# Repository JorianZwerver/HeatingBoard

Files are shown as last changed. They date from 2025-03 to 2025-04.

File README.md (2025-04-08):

# Heating Board PCB

PCB for MOD11 project. Measures current of four channels and can PWM each channel using a PMOS circuit. 

Schematic: [Schematic](Exports/HeatingBoard.pdf) \
Test results: [Results](Testing/2025_03_31_Test_Plan_Heating_Board_Execution.pdf) \
Test code for Arduino Uno: [Code](Testing/test_code.ino)

## Implementation

The board has 5 connectors:

| Connector ID | Description |
| --- | --- |
| J1 | Battery connector, is used for power. |
| J2 | Input interface for control, has a PWM pin for each group and the input for the 3V3 power. |
| J3 | I2C connector, contains SDA, SCL and GND. **However, the GND pin is broken and does not work.** |
| J4 | I2C connector, contains SDA, SCL and GND. |
| J5 | Output to the heating sleeve. Has four outputs and a GND that power the sleeve. |

### Current sensors

The current sensors communicate over the I2C bus. They need 3V3 power, but not battery power. The addresses are stated below:

| Channel number | Address (HEX) | Address (BIN) | Shunt resistor value (mOhm) |
| --- | --- | --- | --- |
| 1 | 0x45 | 1000101 | 101 |
| 2 | 0x44 | 1000100 | 101.2 |
| 3 | 0x41 | 1000001 | 100.5 |
| 4 | 0x40 | 1000000 | 100.6 |

The datasheet can be found using this [link](https://www.ti.com/lit/ds/symlink/ina219.pdf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). We have tested the current sensors in combination with a small load and encountered problems with the PWM, since the current sensor would sometimes measure the full current and sometimes zero current. To solve this, we increased the sample size and PWM frequency. This does mean that the sensor takes ~ 70 ms to get new data. We recommend the following settings:

- 12 bit shunt resolution
- 128 samples per measurement
- 2.5 kHz PWM frequency

We have found pretty accurate results using these settings, only deviating a couple of mW from the power supply. The testing code can be found [here](Testing/test_code.ino). The resistor values of the current shunts are shown in the table with the addresses for the current sensors.

### MOSFETs

During testing, we found that the duty cycle of the output voltage starts deviating from the input duty cycle for higher PWM frequencies. We have tested this for frequencies of 2.5, 5 and 10 kHz and we recommend 2.5 kHz. All results can be found in the [test report](Testing/2025_03_31_Test_Plan_Heating_Board_Execution.pdf).

## 3D Images

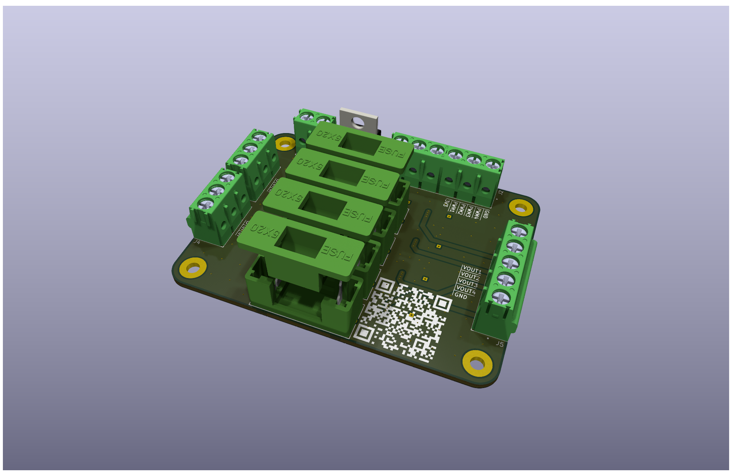
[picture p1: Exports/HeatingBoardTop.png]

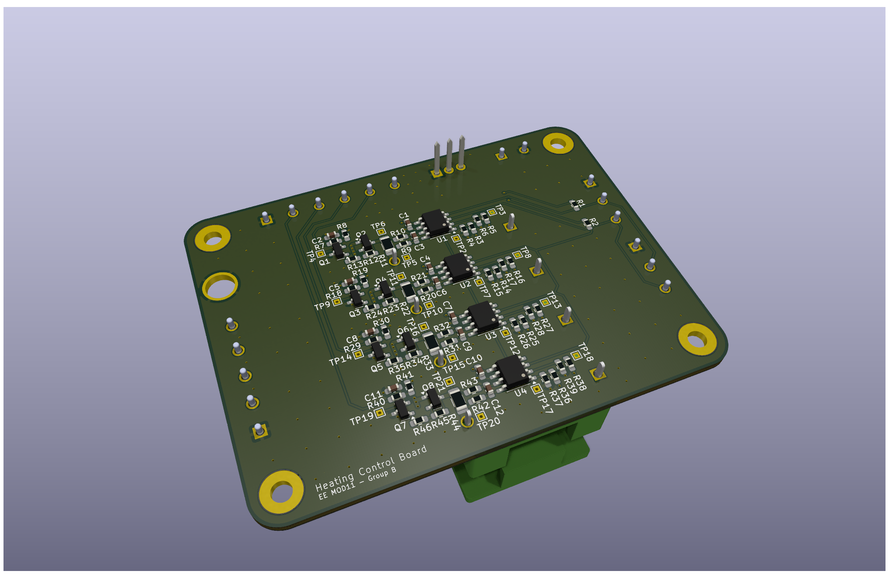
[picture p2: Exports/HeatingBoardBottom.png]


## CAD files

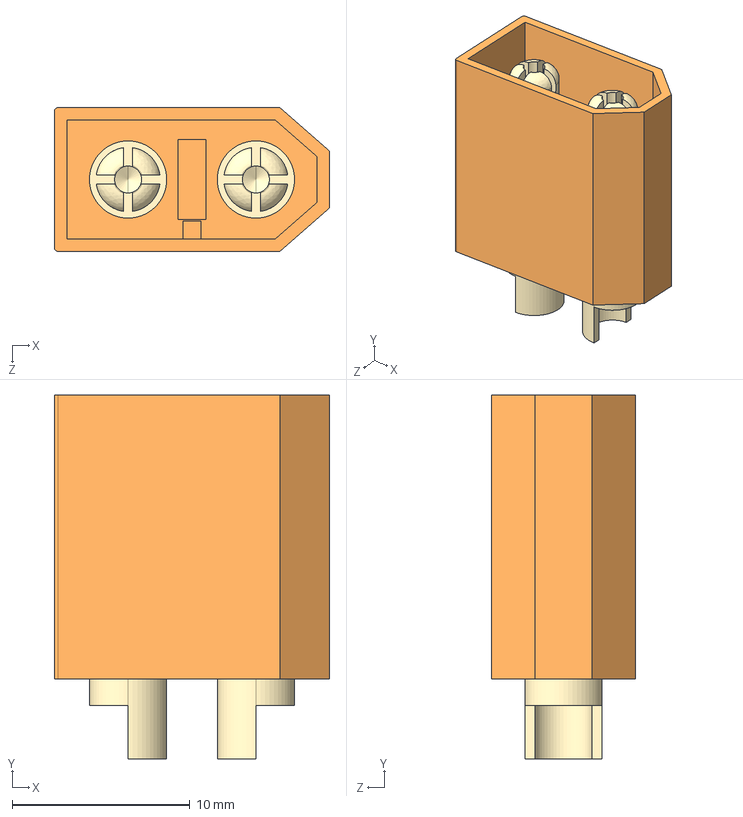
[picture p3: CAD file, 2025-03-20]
HeatingBoard3D/XT60-M.step
15.5 x 20.5 x 8.10 mm

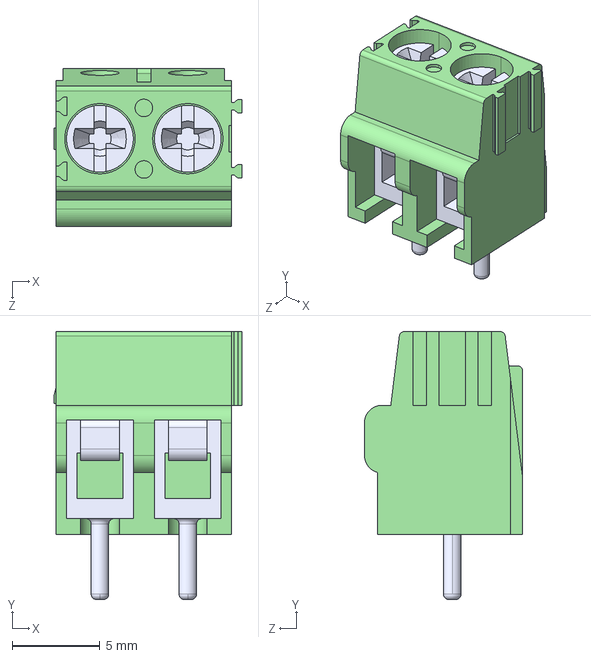
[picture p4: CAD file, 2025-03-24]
HeatingBoard3D/1935161/1935161.step
10.7 x 15.2 x 9.00 mm

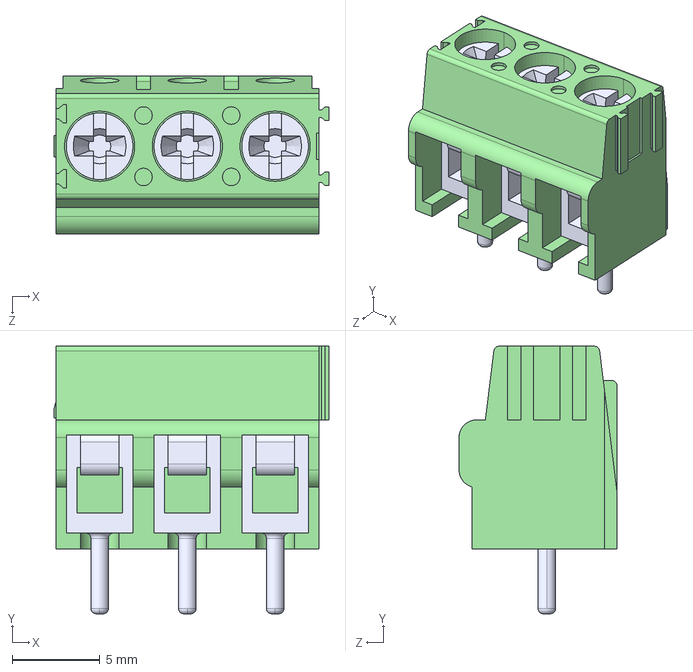
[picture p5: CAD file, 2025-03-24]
HeatingBoard3D/1935174/1935174.step
15.7 x 15.2 x 9.00 mm

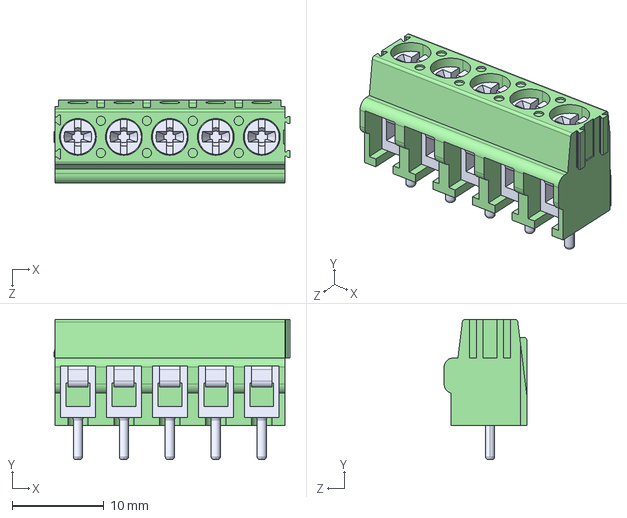
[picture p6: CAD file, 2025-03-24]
HeatingBoard3D/1935190/1935190.step
25.7 x 15.2 x 9.00 mm

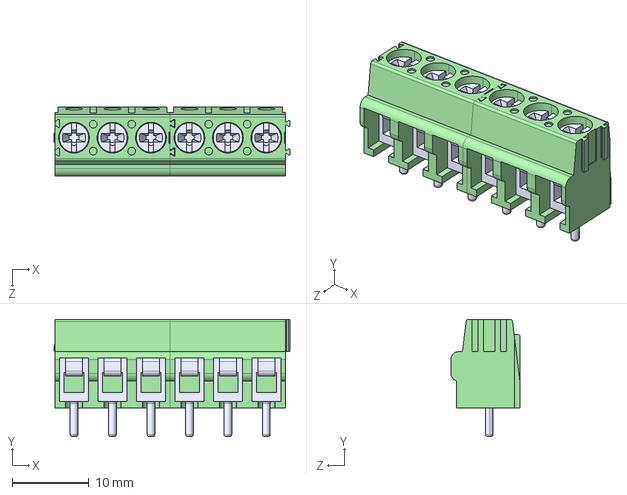
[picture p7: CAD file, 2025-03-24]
HeatingBoard3D/1935200/1935200.step
30.7 x 15.3 x 9.00 mm
1935200_Body_1935174 x 2

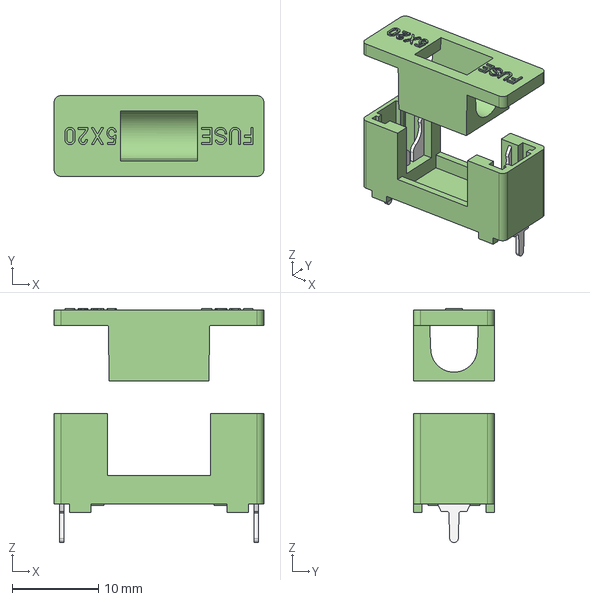
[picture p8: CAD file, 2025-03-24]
HeatingBoard3D/696108003002 (rev1).stp
24.4 x 9.40 x 27.2 mm

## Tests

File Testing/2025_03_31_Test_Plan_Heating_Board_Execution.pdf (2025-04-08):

# Test Plan Heating Board

## Made on March 31st, 2025

Testers: | Jorian Zwerver & Tom Kroeze
Date: | 7th of april 2025
PCB nr.: | 1

## Used devices

Write down below the serial number of the required devices for testing

Benodigdheden | Typenummer
Multimeter | EDU34450A
Power supply | EDU36311A
Load | 2x 200 Ω THT resistors in parallel
Oscilloscope | DSOX1204G

## Hardware testing

### Assembly

Test | Channel 1 | Channel 2 | Channel 3 | Channel 4
Quality of the soldering | Quality of the soldering was good, connection between ground and J3 missing because of a broken pin.
Orientation IC’s | Correct.
Resistor R11 (mΩ) | 101 ± 0.1 | 101.2 ± 0.1 | 100.5 ± 0.1 | 100.6 ± 0.05
No short between 3V3 and GND | Correct.
No short between input and GND | Correct.
No short between output and ground GND | Correct | Correct | Correct | Correct
Resistor between 3V3 and SDA (kΩ) | 2.199
Resistor between 3V3 and | 2.197

SCL (kΩ)

## Power supply

Place 3.3V on J2 and continue the measurements

Test | Channel 1 | Channel 2 | Channel 3 | Channel 4
Measure voltage on IC’s | 3.3V | 3.3V | 3.3V | 3.3V
Measure voltage on TP2 (A1) | 3.3V | 3.3V | 0V | 0V
Measure voltage on Tp3 TP3 (A0) | 3.3V | 0V | 3.3V | 0V

### MOSFETs

Test | Channel 1 | Channel 2 | Channel 3 | Channel 4
Resistor between TP6 and VOUT, PWM = 0V | Open | Open | Open | Open
Resistor between TP6 and VOUT, PWM = 3V3, 0.1 A load | 93 mΩ | 93.5 mΩ | 93.8 mΩ | 92 mΩ

## Function testing

### INA219

Connect the board through the J3 or J4 to the Arduino to test the communication with the INA219 chips.

Test | Channel 1 | Channel 2 | Channel 3 | Channel 4
Test if I2C communication is present | Correct. | Correct. | Correct. | Correct.
Measured current @ 0.1 A (assuming 0.1 Ω resistor) | 0.102 ± 0.001 A | 0.102 ± 0.001 A | 0.099 ± 0.001 A | 0.100 ± 0.001 A

### MOSFETs

Now also connect the J2 to the Arduino to test the MOSFETs. Pull 100 mA with the load. PWM frequency is 5 kHz, duty cycle is at 25%

Test | Channel 1 | Channel 2 | Channel 3 | Channel 4

Measure Vout with an
oscilloscope, is there a
neat squarewave at the
output?
Correct. | Correct. | Correct. | Correct.

## General remarks

Some issues were encountered during testing. Both the issue and the solution will be discussed in this section.

Current sensor measurements in combination with PWM
Due to the use of PWM, the current sensor will sometimes measure no current, and at other moments all the current. This results in an inconsistent measurement. To solve this, the frequency of the PWM is increased and the amount of samples per measurement is increased. This resulted in a better average measurement, which resulted in a current that was of similar accuracy as the power supply.

Used settings:
- 12 bit bus resolution
- 128 samples per measurement
- 5 kHz PWM frequency

Turn-off time PMOS
With the initial testing, at a frequency of around 5 kHz, the turnoff speed of the mosfet was slower than expected. This resulted in the actual duty cycle not properly aligning with the input duty cycle. Because it was slower than expected, the output duty cycle ended up being higher than the input duty cycle which should not be the case. This effect is shown in figures 1 and 2. To prevent this effect from happening, firstly R13 was set to 0Ω and R12 was changed to a 2.2kΩ resistor. Changing these resistors should lead to the Mosfet discharging faster, thus reducing the turn-off time. This seemed to resolve the issue, however, when measuring the 4th channel the current sensor values were producing confusing results. We believe this was caused by some EMI problems by very high turn-off or turn-on times. Because of this, the 0Ω resistor was changed to a 2.2kΩ resistor which solved the problem. This resulted in figures 3 to 6.

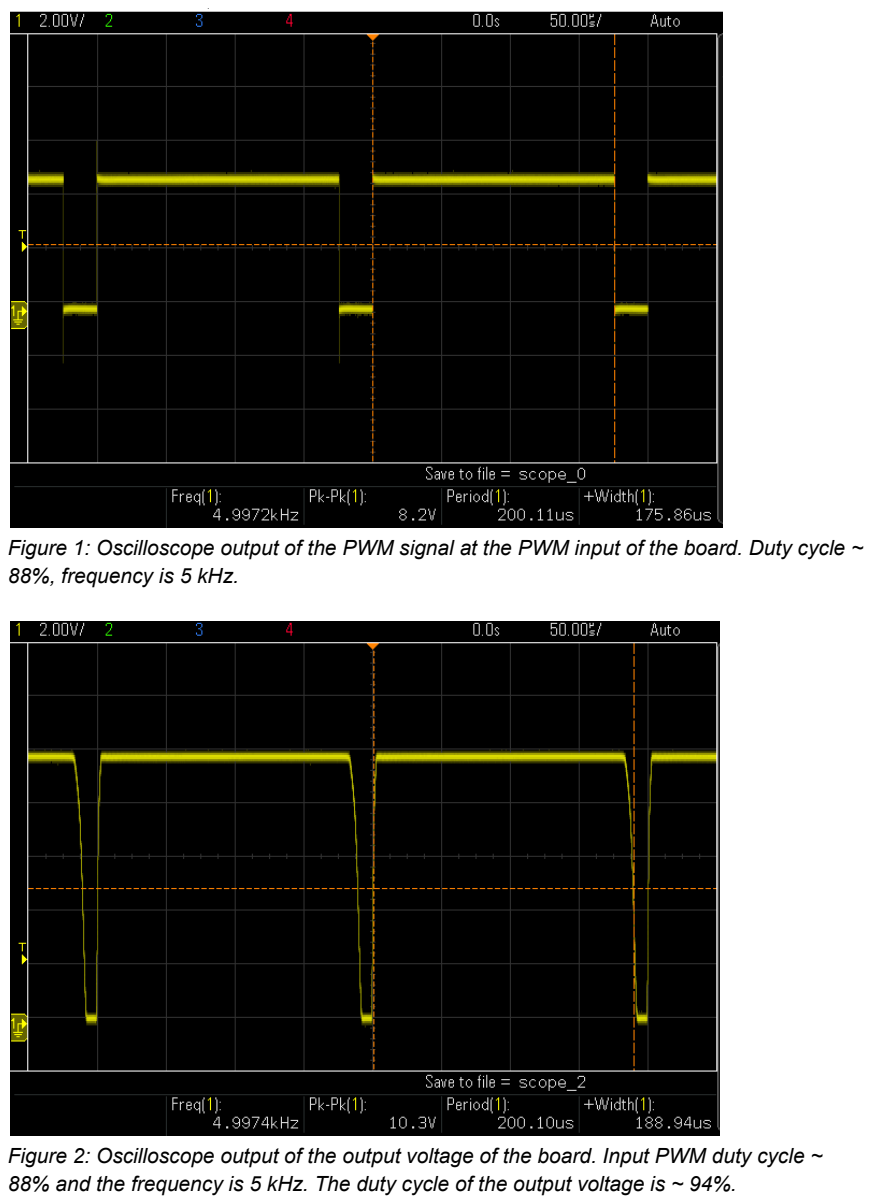
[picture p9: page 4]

Figure 1: Oscilloscope output of the PWM signal at the PWM input of the board. Duty cycle ~ 88%, frequency is 5 kHz.

Figure 2: Oscilloscope output of the output voltage of the board. Input PWM duty cycle ~ 88% and the frequency is 5 kHz. The duty cycle of the output voltage is ~ 94%.

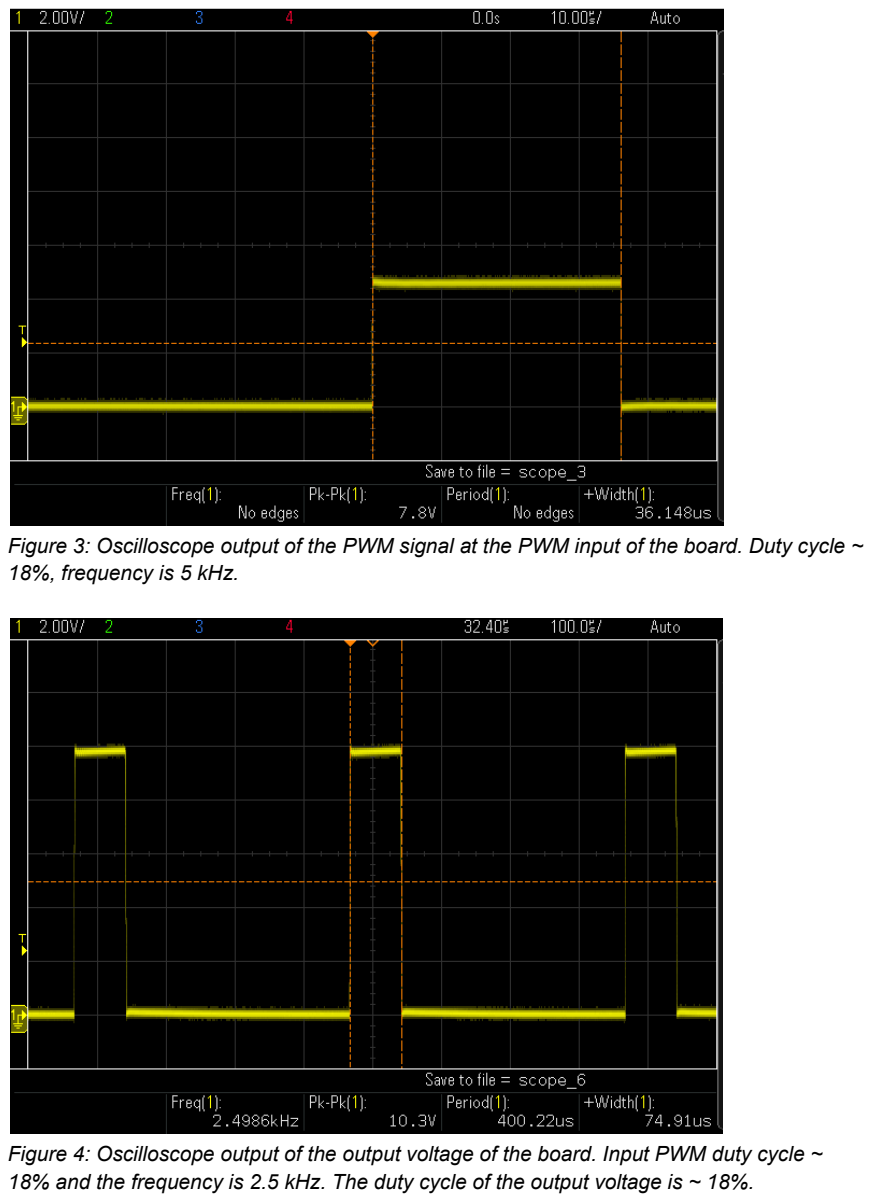
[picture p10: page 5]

Figure 3: Oscilloscope output of the PWM signal at the PWM input of the board. Duty cycle ~ 18%, frequency is 5 kHz.

Figure 4: Oscilloscope output of the output voltage of the board. Input PWM duty cycle ~ 18% and the frequency is 2.5 kHz. The duty cycle of the output voltage is ~ 18%.

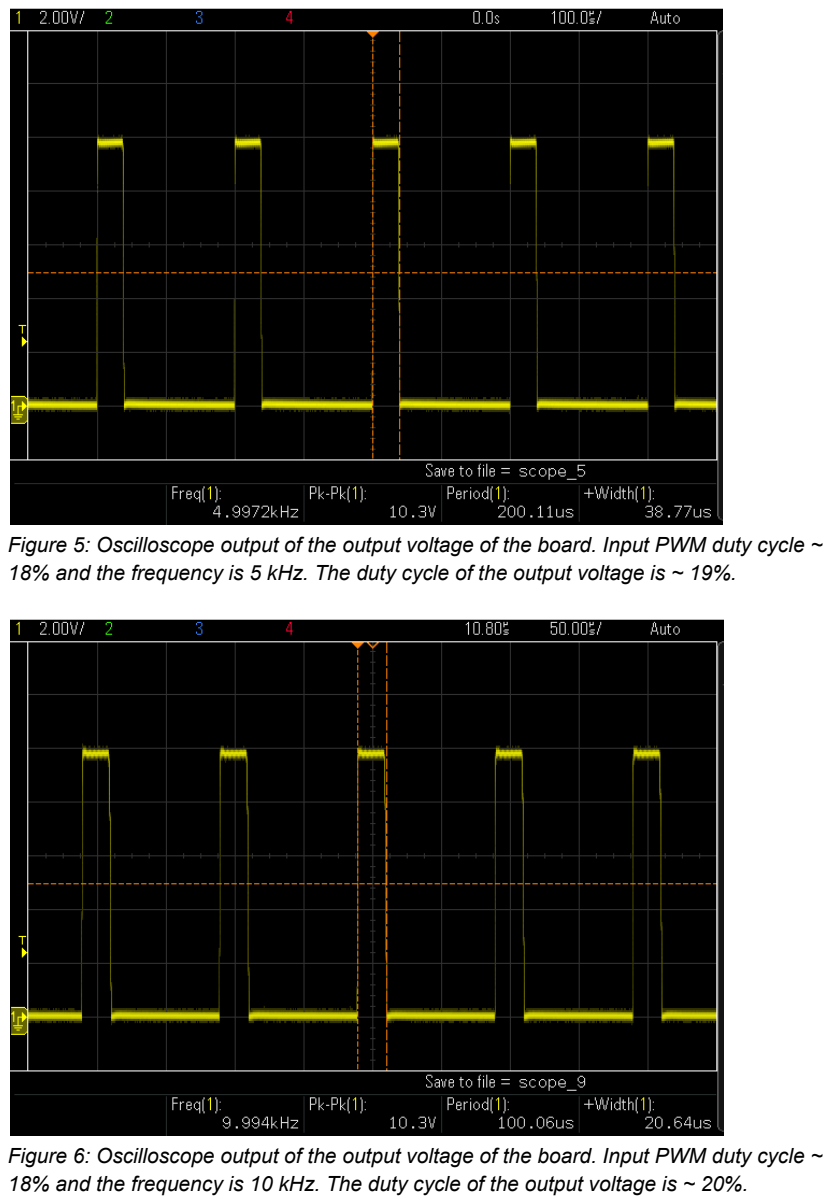
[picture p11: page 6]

Figure 5: Oscilloscope output of the output voltage of the board. Input PWM duty cycle ~ 18% and the frequency is 5 kHz. The duty cycle of the output voltage is ~ 19%.

Figure 6: Oscilloscope output of the output voltage of the board. Input PWM duty cycle ~ 18% and the frequency is 10 kHz. The duty cycle of the output voltage is ~ 20%.

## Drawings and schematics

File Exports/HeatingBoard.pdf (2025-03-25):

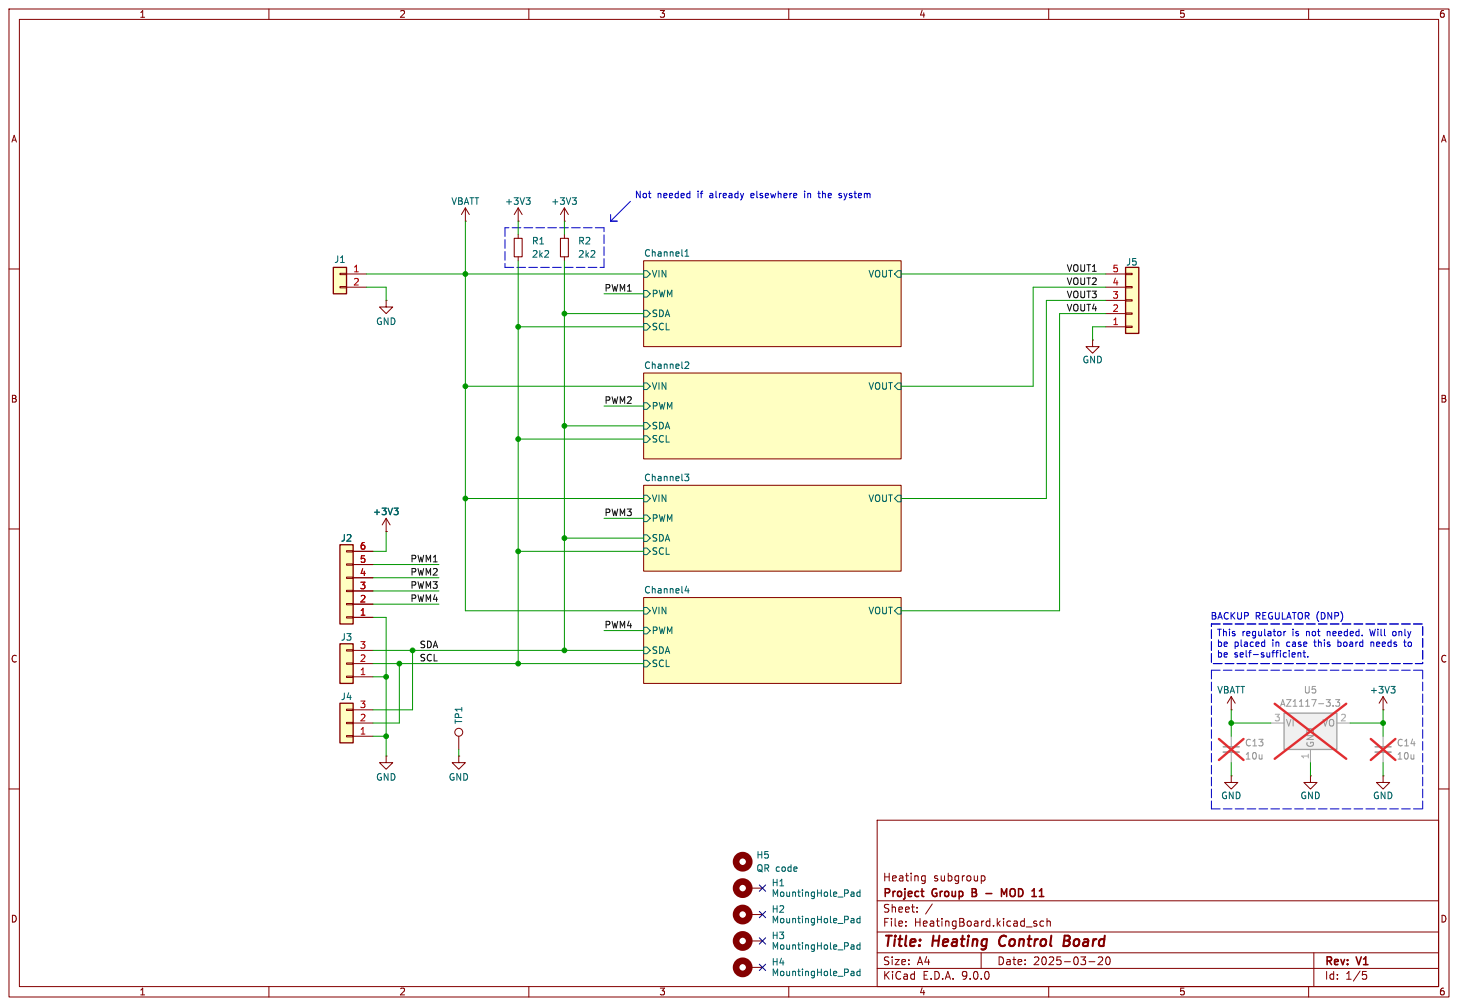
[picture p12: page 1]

be self-sufficient. Not needed if already elsewhere in the system

Id: 1/5 Title: Heating Control Board

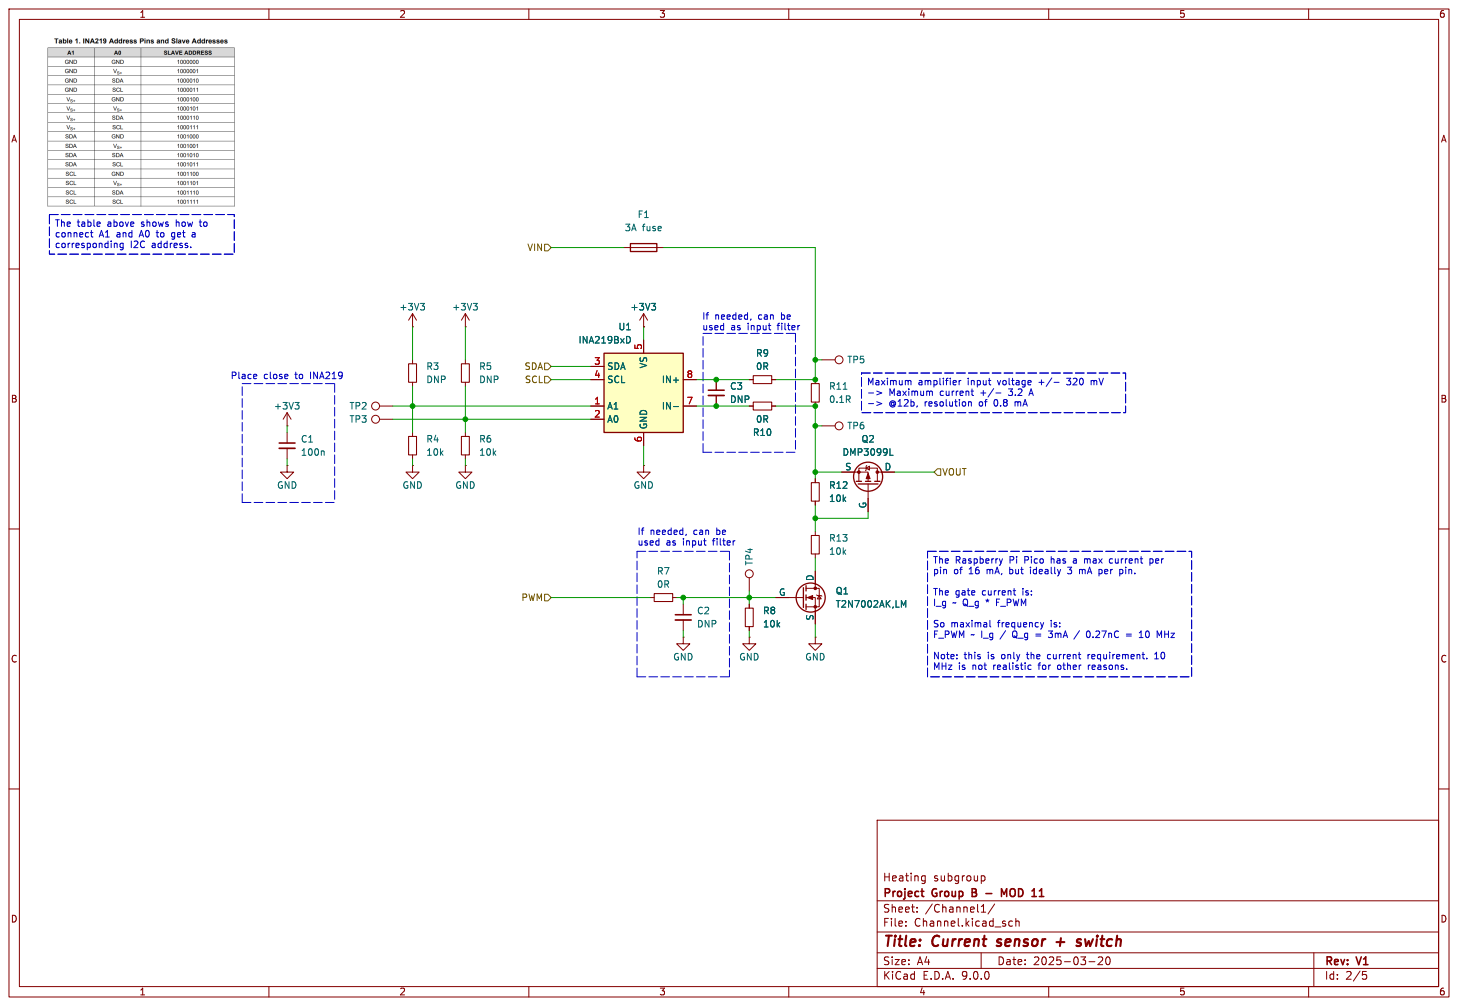
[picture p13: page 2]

The table above shows how to
connect A1 and A0 to get a

used as input filter +3V3 U1

If needed, can be
used as input filter

The Raspberry Pi Pico has a max current per pin of 16 mA, but ideally 3 mA per pin. The gate current is:

Id: 2/5 Title: Current sensor + switch

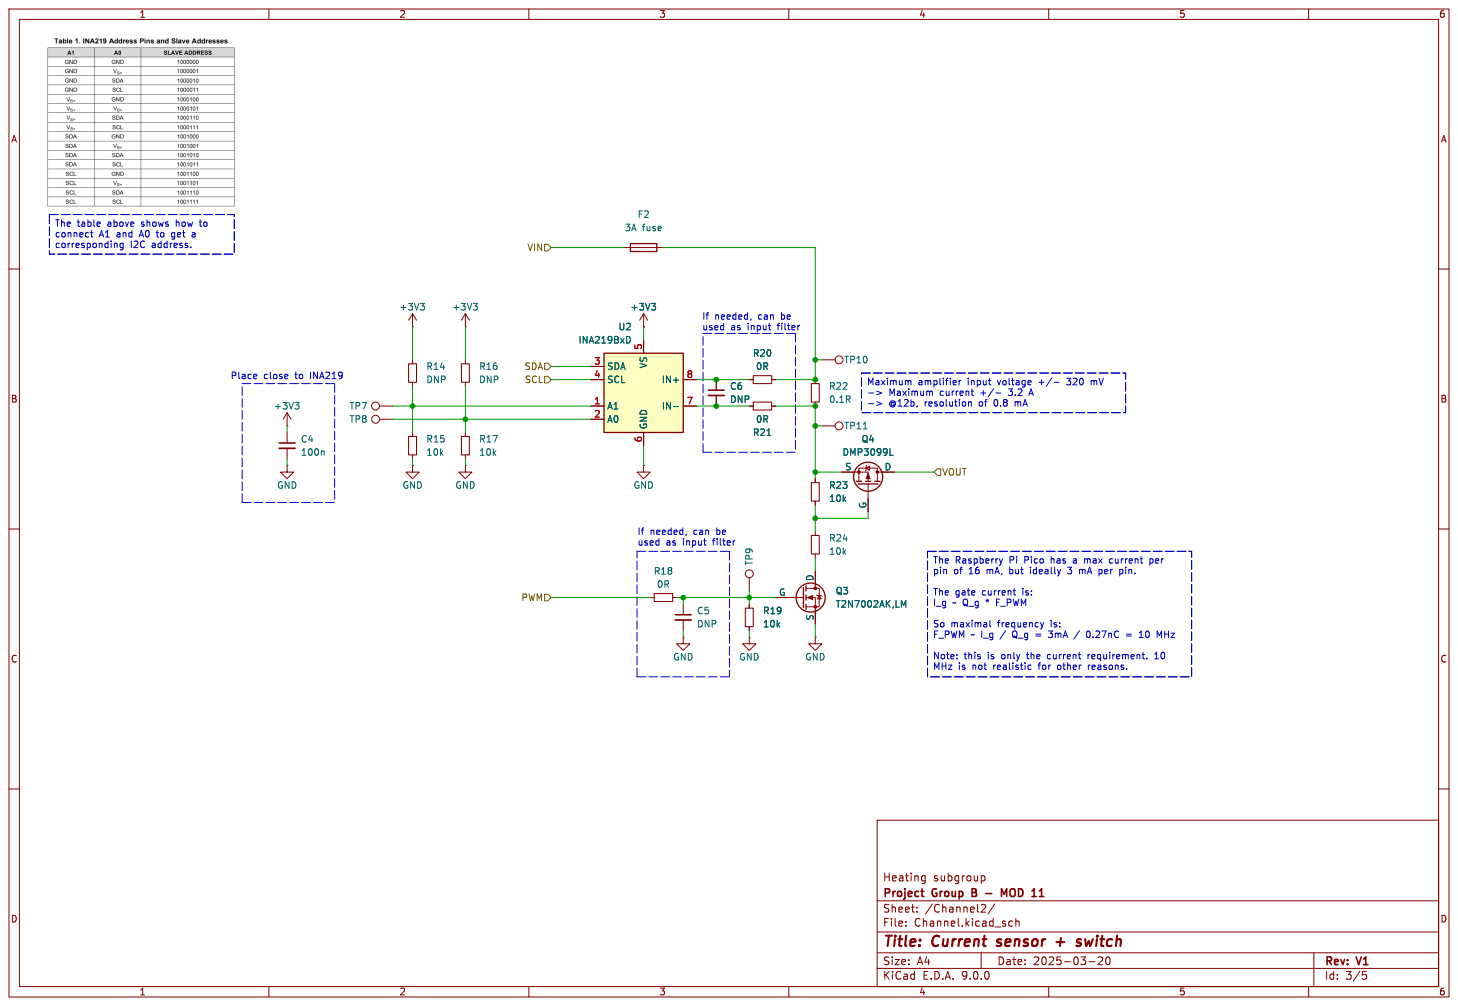
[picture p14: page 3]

The table above shows how to
connect A1 and A0 to get a

If needed, can be
used as input filter

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

Id: 3/5 Title: Current sensor + switch

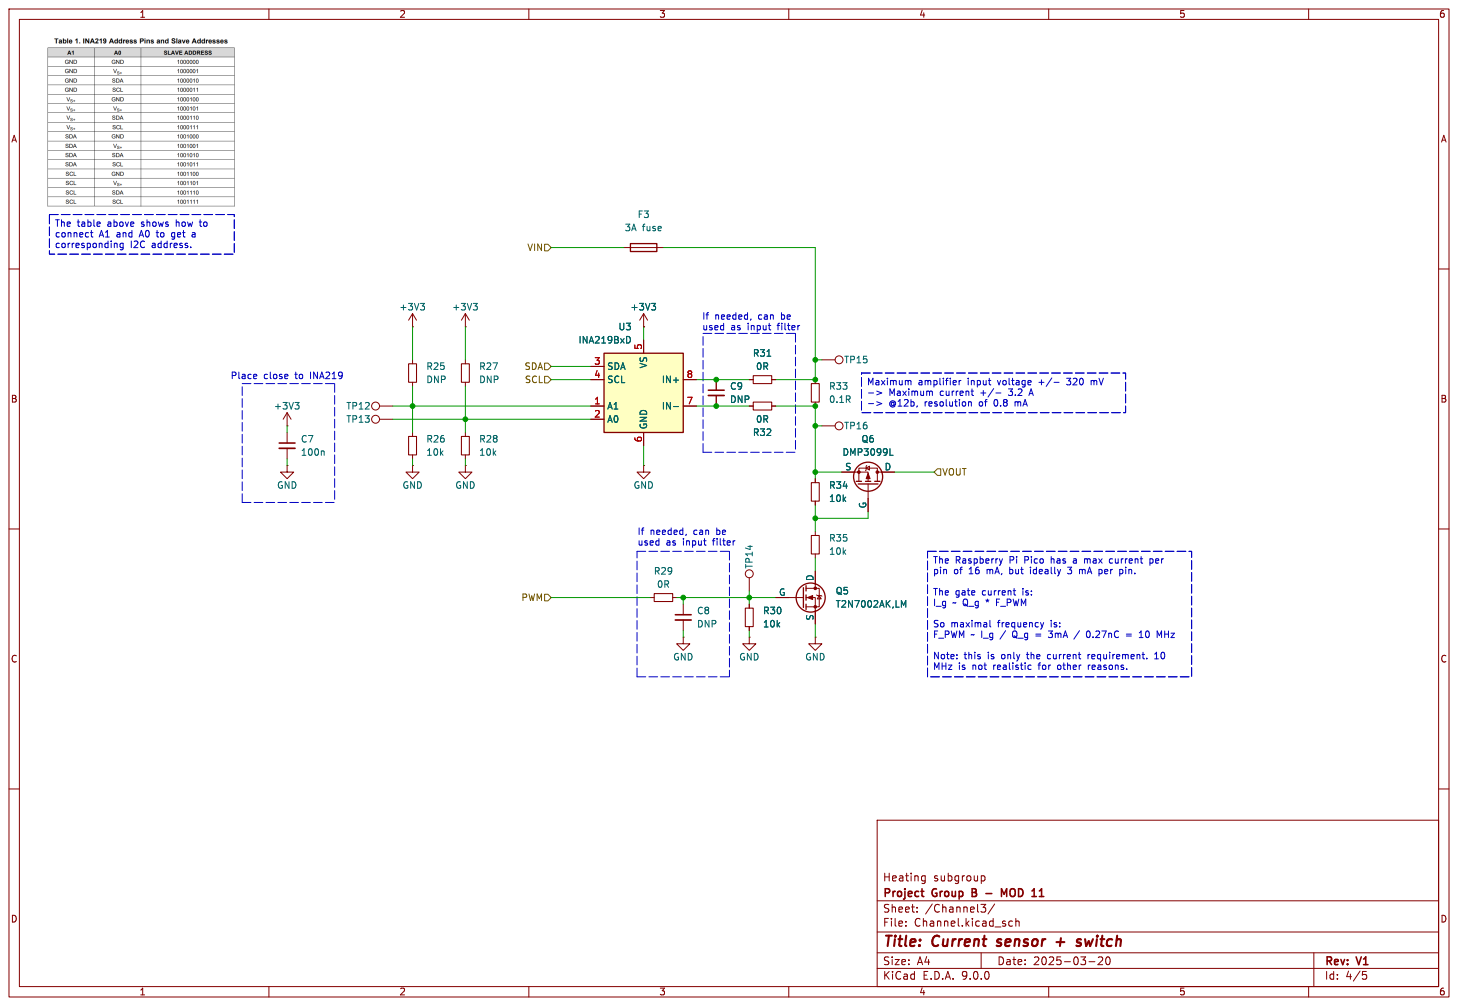
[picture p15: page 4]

The table above shows how to
connect A1 and A0 to get a

used as input filter +3V3 U3

If needed, can be
used as input filter

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

Id: 4/5 Title: Current sensor + switch

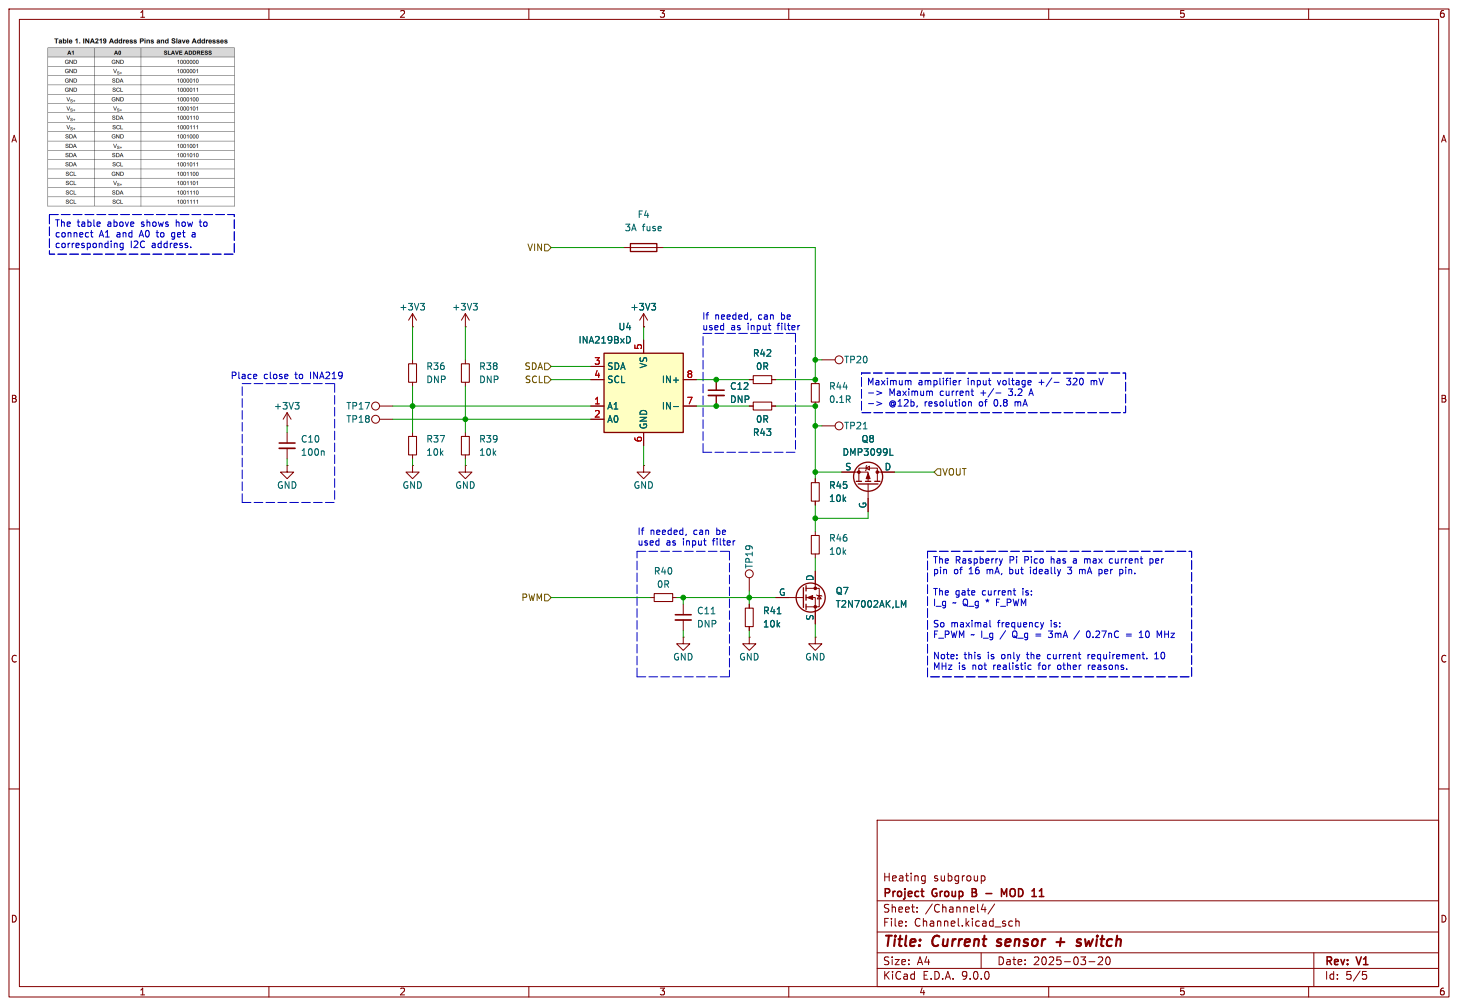
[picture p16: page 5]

The table above shows how to
connect A1 and A0 to get a

If needed, can be
used as input filter

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

Id: 5/5 Title: Current sensor + switch

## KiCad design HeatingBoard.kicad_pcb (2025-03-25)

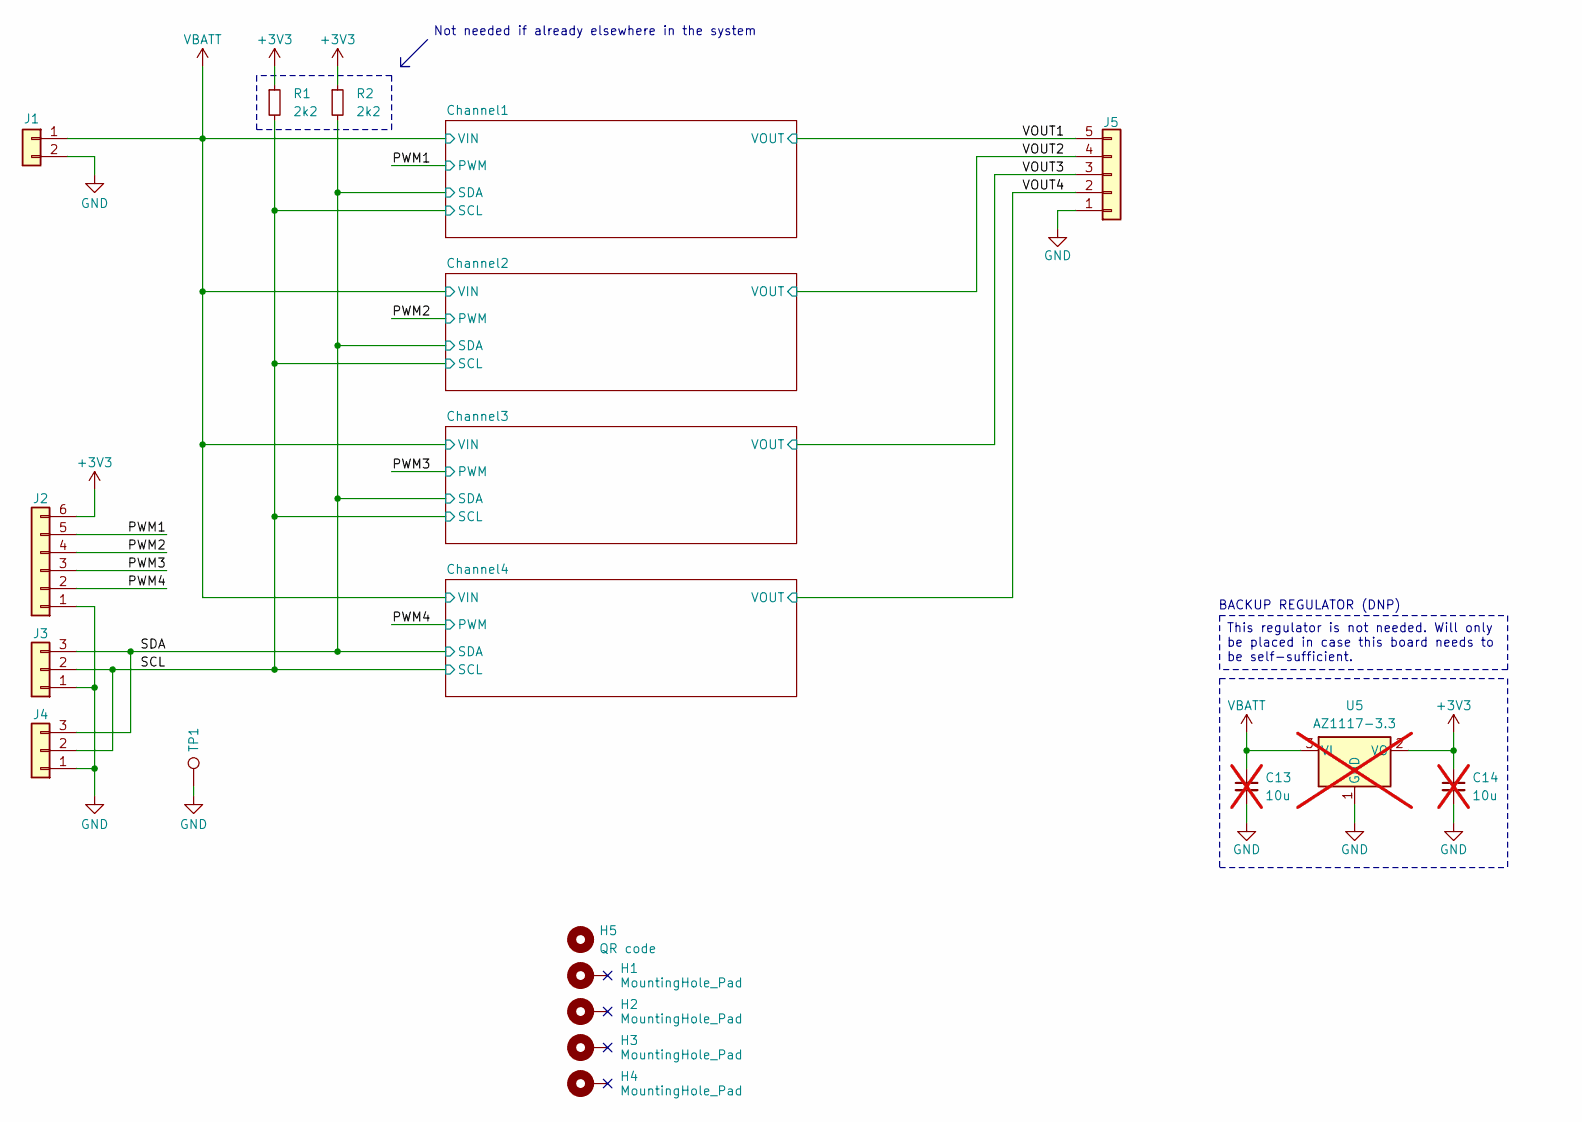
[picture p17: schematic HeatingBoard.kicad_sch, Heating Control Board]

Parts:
C13, C14: 10u; C_0805_2012Metric_Pad1.18x1.45mm_HandSolder; not fitted
H1, H2, H3, H4: MountingHole_Pad; MountingHole_3.2mm_M3_Pad
H5: QR code; QRcode
J1: Conn_01x02; PHOENIX_1935161
J2: Conn_01x06; PHOENIX_1935200
J3, J4: Conn_01x03; PHOENIX_1935174
J5: Conn_01x05; PHOENIX_1935190
R1, R2: 2k2; R_0603_1608Metric_Pad0.98x0.95mm_HandSolder
TP1: TestPoint; TestPoint_Plated_Hole_D5.0mm
U5: AZ1117-3.3; TO-220-3_Vertical; not fitted

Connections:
+3V3: C14.1, J2.6, R1.1, R2.1, U5.2 (VO); also elsewhere on the board
/PWM1: J2.5; also elsewhere on the board
/PWM2: J2.4; also elsewhere on the board
/PWM3: J2.3; also elsewhere on the board
/PWM4: J2.2; also elsewhere on the board
/SCL: J3.2, J4.2, R1.2; also elsewhere on the board
/SDA: J3.3, J4.3, R2.2; also elsewhere on the board
/VOUT1: J5.5; also elsewhere on the board
/VOUT2: J5.4; also elsewhere on the board
/VOUT3: J5.3; also elsewhere on the board
/VOUT4: J5.2; also elsewhere on the board
GND: C13.2, C14.2, J1.2, J2.1, J3.1, J4.1, J5.1, TP1.1, U5.1 (GND); also elsewhere on the board
VBATT: C13.1, J1.1, U5.3 (VI); also elsewhere on the board

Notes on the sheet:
BACKUP REGULATOR (DNP)
Not needed if already elsewhere in the system
This regulator is not needed. Will only be placed in case this board needs to be self-sufficient.

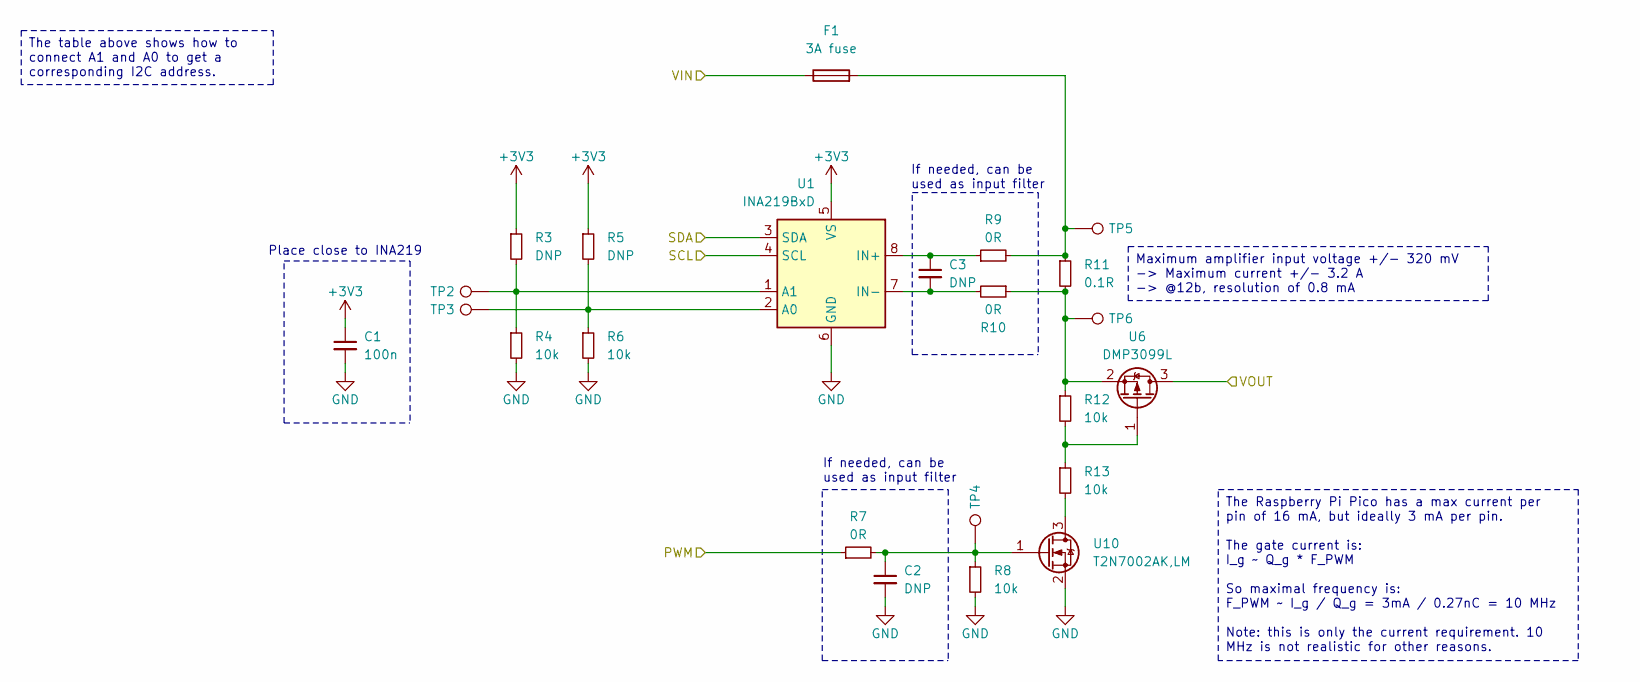
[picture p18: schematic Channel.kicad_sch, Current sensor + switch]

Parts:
C1: 100n; C_0603_1608Metric_Pad1.08x0.95mm_HandSolder
C2, C3: DNP; C_0603_1608Metric_Pad1.08x0.95mm_HandSolder
F1: 3A fuse; FUSE_0PTF0078P_LTF
R3, R5: DNP; R_0603_1608Metric_Pad0.98x0.95mm_HandSolder
R4, R6, R8, R12, R13: 10k; R_0603_1608Metric_Pad0.98x0.95mm_HandSolder
R7, R9, R10: 0R; R_0603_1608Metric_Pad0.98x0.95mm_HandSolder
R11: 0.1R; R_1206_3216Metric_Pad1.30x1.75mm_HandSolder
TP2, TP3, TP4, TP5, TP6: TestPoint; TestPoint_THTPad_1.0x1.0mm_Drill0.5mm
U1: INA219BxD; SOIC-8_3.9x4.9mm_P1.27mm
U6: DMP3099L; SOT-23
U10: T2N7002AK,LM; SOT-23

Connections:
+3V3: C1.1, R3.1, R5.1, U1.5 (VS); also elsewhere on the board
/PWM1: R7.1; also elsewhere on the board
/SCL: U1.4 (SCL); also elsewhere on the board
/SDA: U1.3 (SDA); also elsewhere on the board
/VOUT1: U6.3; also elsewhere on the board
GND: C1.2, C2.2, R4.2, R6.2, R8.2, U1.6 (GND), U10.2; also elsewhere on the board
unnamed: C2.1, R7.2, R8.1, TP4.1, U10.1
unnamed: F1.2, R9.2, R11.1, TP5.1
unnamed: R10.1, R11.2, R12.1, TP6.1, U6.2
unnamed: R12.2, R13.1, U6.1
unnamed: R13.2, U10.3
unnamed: R5.2, R6.1, TP3.1, U1.2 (A0)
unnamed: R3.2, R4.1, TP2.1, U1.1 (A1)
unnamed: C3.1, R9.1, U1.8 (IN+)
unnamed: C3.2, R10.2, U1.7 (IN-)
VBATT: F1.1; also elsewhere on the board

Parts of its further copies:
C4, C7, C10: 100n; C_0603_1608Metric_Pad1.08x0.95mm_HandSolder
C5, C6, C8, C9, C11, C12: DNP; C_0603_1608Metric_Pad1.08x0.95mm_HandSolder
F2, F3, F4: 3A fuse; FUSE_0PTF0078P_LTF
R14, R16, R25, R27, R36, R38: DNP; R_0603_1608Metric_Pad0.98x0.95mm_HandSolder
R15, R17, R19, R23, R24, R26, R28, R30, R34, R35, R37, R39, R41, R45, R46: 10k; R_0603_1608Metric_Pad0.98x0.95mm_HandSolder
R18, R20, R21, R29, R31, R32, R40, R42, R43: 0R; R_0603_1608Metric_Pad0.98x0.95mm_HandSolder
R22, R33, R44: 0.1R; R_1206_3216Metric_Pad1.30x1.75mm_HandSolder
TP7, TP8, TP9, TP10, TP11, TP12, TP13, TP14, TP15, TP16, TP17, TP18, TP19, TP20, TP21: TestPoint; TestPoint_THTPad_1.0x1.0mm_Drill0.5mm
U2, U3, U4: INA219BxD; SOIC-8_3.9x4.9mm_P1.27mm
U7, U8, U9: DMP3099L; SOT-23
U11, U12, U13: T2N7002AK,LM; SOT-23

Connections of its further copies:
+3V3: C4.1, C7.1, C10.1, R14.1, R16.1, R25.1, R27.1, R36.1, R38.1, U2.5 (VS), U3.5 (VS), U4.5 (VS); also elsewhere on the board
/PWM2: R18.1; also elsewhere on the board
/PWM3: R29.1; also elsewhere on the board
/PWM4: R40.1; also elsewhere on the board
/SCL: U2.4 (SCL), U3.4 (SCL), U4.4 (SCL); also elsewhere on the board
/SDA: U2.3 (SDA), U3.3 (SDA), U4.3 (SDA); also elsewhere on the board
/VOUT2: U7.3; also elsewhere on the board
/VOUT3: U8.3; also elsewhere on the board
/VOUT4: U9.3; also elsewhere on the board
GND: C4.2, C5.2, C7.2, C8.2, C10.2, C11.2, R15.2, R17.2, R19.2, R26.2, R28.2, R30.2, R37.2, R39.2, R41.2, U2.6 (GND), U3.6 (GND), U4.6 (GND), U11.2, U12.2, U13.2; also elsewhere on the board
unnamed: C5.1, R18.2, R19.1, TP9.1, U11.1
unnamed: C8.1, R29.2, R30.1, TP14.1, U12.1
unnamed: C11.1, R40.2, R41.1, TP19.1, U13.1
unnamed: F2.2, R20.2, R22.1, TP10.1
unnamed: F3.2, R31.2, R33.1, TP15.1
unnamed: F4.2, R42.2, R44.1, TP20.1
unnamed: R21.1, R22.2, R23.1, TP11.1, U7.2
unnamed: R23.2, R24.1, U7.1
unnamed: R24.2, U11.3
unnamed: R32.1, R33.2, R34.1, TP16.1, U8.2
unnamed: R34.2, R35.1, U8.1
unnamed: R35.2, U12.3
unnamed: R43.1, R44.2, R45.1, TP21.1, U9.2
unnamed: R45.2, R46.1, U9.1
unnamed: R46.2, U13.3
unnamed: R16.2, R17.1, TP8.1, U2.2 (A0)
unnamed: R14.2, R15.1, TP7.1, U2.1 (A1)
unnamed: C6.1, R20.1, U2.8 (IN+)
unnamed: C6.2, R21.2, U2.7 (IN-)
unnamed: R27.2, R28.1, TP13.1, U3.2 (A0)
unnamed: R25.2, R26.1, TP12.1, U3.1 (A1)
unnamed: C9.1, R31.1, U3.8 (IN+)
unnamed: C9.2, R32.2, U3.7 (IN-)
unnamed: R38.2, R39.1, TP18.1, U4.2 (A0)
unnamed: R36.2, R37.1, TP17.1, U4.1 (A1)
unnamed: C12.1, R42.1, U4.8 (IN+)
unnamed: C12.2, R43.2, U4.7 (IN-)
VBATT: F2.1, F3.1, F4.1; also elsewhere on the board

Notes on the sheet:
Place close to INA219
If needed, can be used as input filter
Maximum amplifier input voltage +/- 320 mV -> Maximum current +/- 3.2 A -> @12b, resolution of 0.8 mA
The Raspberry Pi Pico has a max current per pin of 16 mA, but ideally 3 mA per pin. The gate current is: I_g ~ Q_g * F_PWM So maximal frequency is: F_PWM ~ I_g / Q_g = 3mA / 0.27nC = 10 MHz Note: this is only the current requirement. 10 MHz is not realistic for other reasons.
The table above shows how to connect A1 and A0 to get a corresponding I2C address.

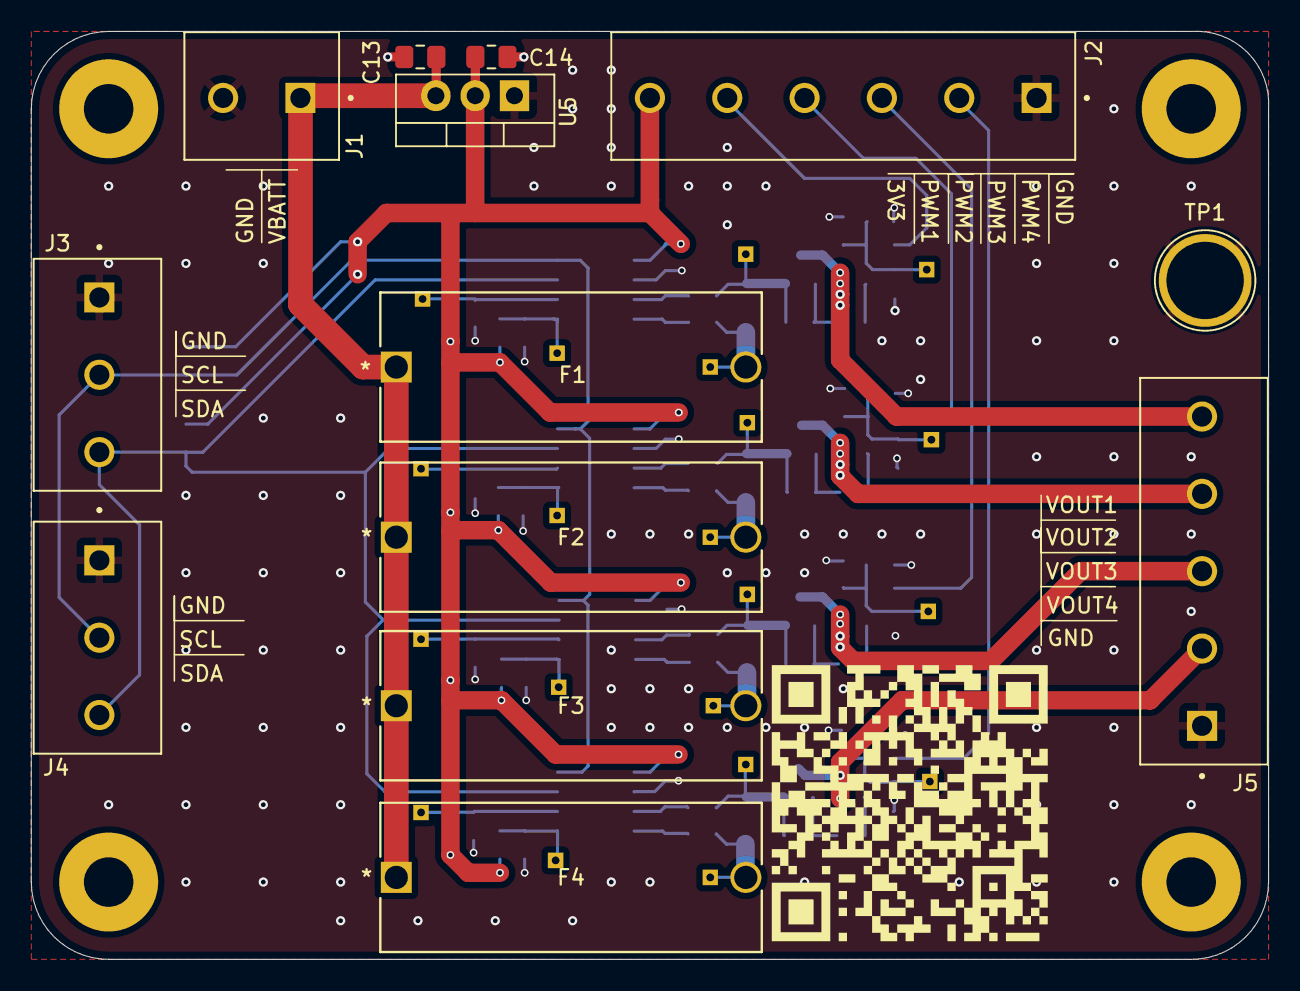
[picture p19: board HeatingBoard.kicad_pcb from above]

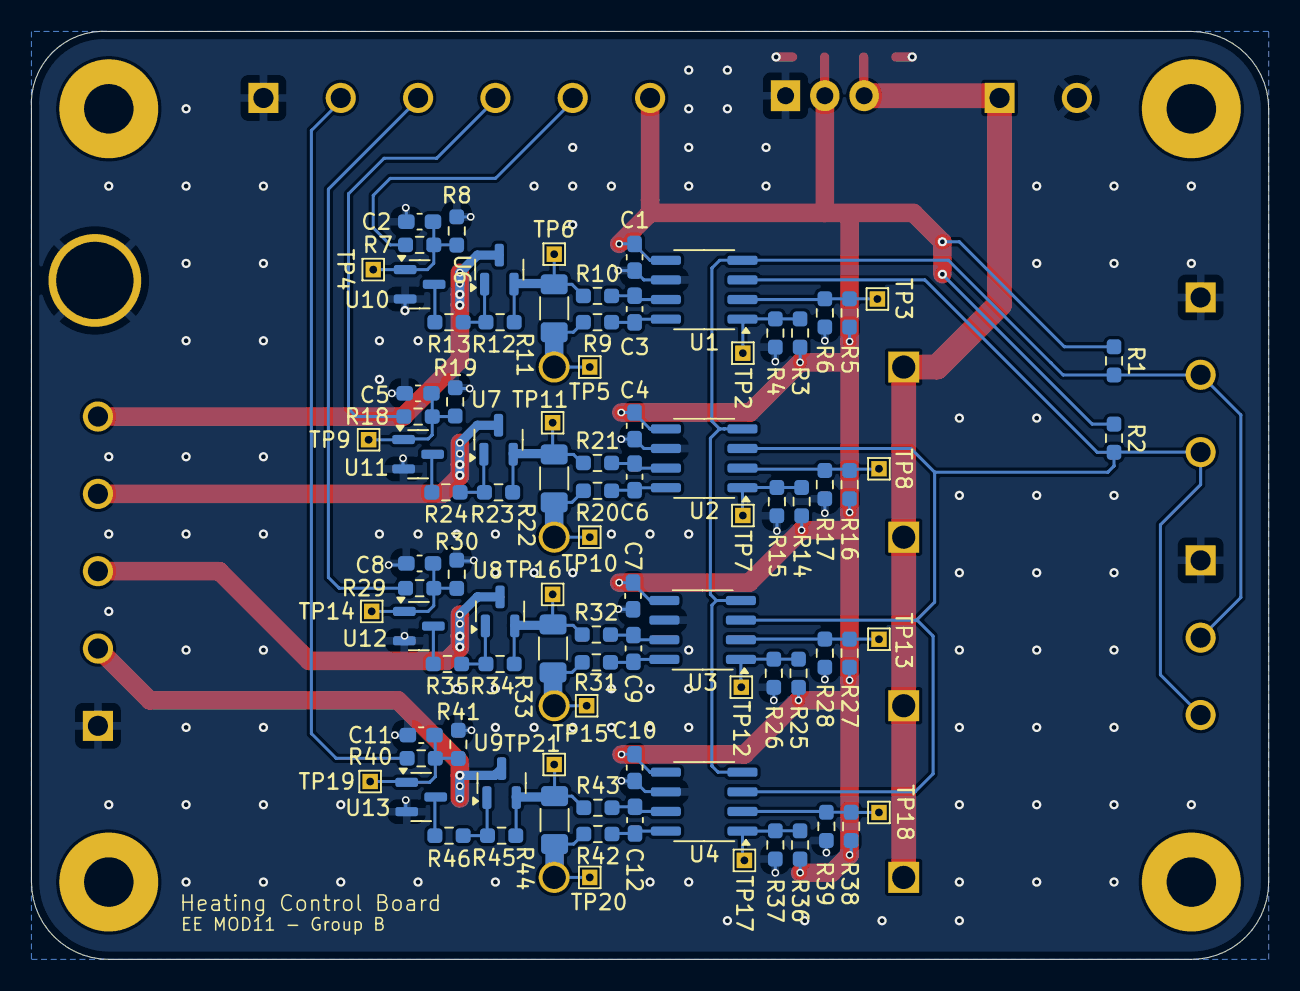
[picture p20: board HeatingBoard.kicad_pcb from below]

Board: 2 copper layers, 80.0 x 60.0 mm, 108 parts (90 on the bottom side), 49 nets.

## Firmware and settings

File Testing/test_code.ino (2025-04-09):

// Arduino led pin
#define LED_PIN 13

// Only one channel was tested at a time
#define PWM_CH1 9

// I2C addresses for current sensors
#define CHANNEL4 0x40
#define CHANNEL3 0x41
#define CHANNEL2 0x44
#define CHANNEL1 0x45

// Channel count
#define CHANNELS_LENGTH 4

#include <INA219.h>
#include <TimerOne_V2.h>

// Define all current sensors
INA219 channels[CHANNELS_LENGTH] = {
  INA219(CHANNEL1),
  INA219(CHANNEL2),
  INA219(CHANNEL3),
  INA219(CHANNEL4)
};

void setup() {

    pinMode(LED_PIN, OUTPUT);

    // Set PWM frequency to 2.5 kHz
    Timer1.frequency(2.5);
    Serial.begin(9600);
    // Start I2C
    Wire.begin();

    // Check if all chips are presents
    for(int i = 0; i < CHANNELS_LENGTH; i++) {

        if(!channels[i].begin()) {
            Serial.print("Could not connect to INA219, channel ");
            Serial.print(i);
            Serial.println("!");
            while(1){delay(10);}
        }

        // Set current shunt values and sensor parameters
        channels[i].setMaxCurrentShunt(1.0, 0.1);
        channels[i].setShuntResolution(12);
        channels[i].setShuntSamples(7);
    }

}

void loop() {
  
    // Blink LED for performance
    digitalWrite(LED_PIN, HIGH);
    delay(100);
    digitalWrite(LED_PIN, LOW);
        
    // Set PWM duty cycle to ~ 18%
    Timer1.pwm(PWM_CH1, 185);

    // Print all sensor values to serial
    Serial.println("\n\t#\tBUS\t\tSHUNT\t\tCURRENT\t\tPOWER");
    for (int i = 0; i < CHANNELS_LENGTH; i++)
    {
        Serial.print("\t");
        Serial.print(i);
        Serial.print("\t");
        Serial.print(channels[i].getBusVoltage(), 2);
        Serial.print("\t\t");
        Serial.print(channels[i].getShuntVoltage_mV(), 2);
        Serial.print("\t\t");
        Serial.print(channels[i].getCurrent_mA(), 2);
        Serial.print("\t\t");
        Serial.print(channels[i].getPower_mW(), 2);
        Serial.println();
        delay(200);
    }
    delay(3000);

}

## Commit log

2025-03-23 Finished PCB
    [Channel.kicad_sch, HeatingBoard.kicad_pcb, HeatingBoard.kicad_sch]
2025-03-24 Added 3D models
    [1935161.step, 1935174.step, 1935190.step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]
2025-03-24 Added QR code and images
    [Channel.kicad_sch, HeatingBoard.kicad_pcb]
2025-03-25 Full review
    Notes in README. TLDR: MOSFET footprint pinouts are incorrect
2025-03-25 Fixed review comments
    [Channel.kicad_sch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]
2025-04-08 Updated readme and addes test results
    [HeatingBoard.kicad_pcb]
2025-04-09 Changed max current in test code
